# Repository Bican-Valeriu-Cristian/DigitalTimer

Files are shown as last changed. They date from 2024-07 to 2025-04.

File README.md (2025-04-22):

# Digital Timer

The project involves a digital timer that counts up to one minute. Each counter's 4-bit output is fed into a binary-to-7-segment decoder, enabling number display on 7-segment displays. 
The circuit includes switches for starting/stopping the timer and resetting the count.

WhatsApp Image 2024-07-15 at 16 40 44_299e31ab

## Description

This circuit diagram represents a digital timer capable of counting seconds up to one minute. The circuit operates by generating a clock signal with a precise frequency of 1 Hz (once per second) using an oscillator based on the NE555 timer. This signal is connected to the count-up input of an integrated circuit counter. Since the counter dedicated to seconds has a 4-bit output, it can count up to 15. Therefore, it requires conditioning with logic circuits to prevent it from exceeding the value of 10. Each time this number is reached, a count-up signal is also sent to a second counter dedicated to tens of seconds. This counter also requires logic conditioning, but this time up to the value of 6.

The 4 bits produced by each counter are then fed into a binary-to-7-segment decoder, which finally allows the numbers to be displayed on 7-segment displays. Additionally, the circuit includes two switches, one for starting and stopping the timer and another for resetting the count.

## Contents

| File/folder | Description |
|---|---|
| `PCB.kicad_sch` | Schematic |
| `PCB.kicad_pcb` | PCB editor |
| `gerber` | Altium Designer schematics, PCB layout, and supporting project files
| `README.md` | This README file. |
| `LICENSE` | The license for the project. |

## Tools

First step:
The schematic for this project was created using KiCad software.


Next was drawing the layout:

  -The PCB is a 8 cm x 8 cm 2-layer board.

  -It has a GND copper plane on both layers.

  -All signal traces are 0.254 mm, while the 5V power trace is double the size, at 0.508 mm.

  -Proper names were added for the various components, along with description text and a nice drawing.

  

The final steps were to order the parts, the PCB, and assemble the board.

  -The various components were ordered from TME
  
  -The PCB was ordered from Jlcpcb

## Bill of materials

-2x 7-segment displays

-2x 10nF ceramic capacitors

-1x 1uF electrolytic capacitor

-2x push switches

-2x header pins

-2x 4-bit tri-state registers

-2x 4-bit BCD decoders

-2x 4-bit counters

-2x quad AND gate chips

-1x quad NOR gate chip

-1x dual JK flip-flop chip

-Various resistors

## Final statistics
  
Total hours of work:

  Designing schematic and testing: 3 hours
  
  Making layout: 3 hours
  
  Assembling PCB: 5 hours

## Extra photos

WhatsApp Image 2024-07-15 at 16 51 08_b6c535b6

WhatsApp Image 2024-07-15 at 16 51 08_239efd22

## License

For details on license, see LICENSE in this directory.

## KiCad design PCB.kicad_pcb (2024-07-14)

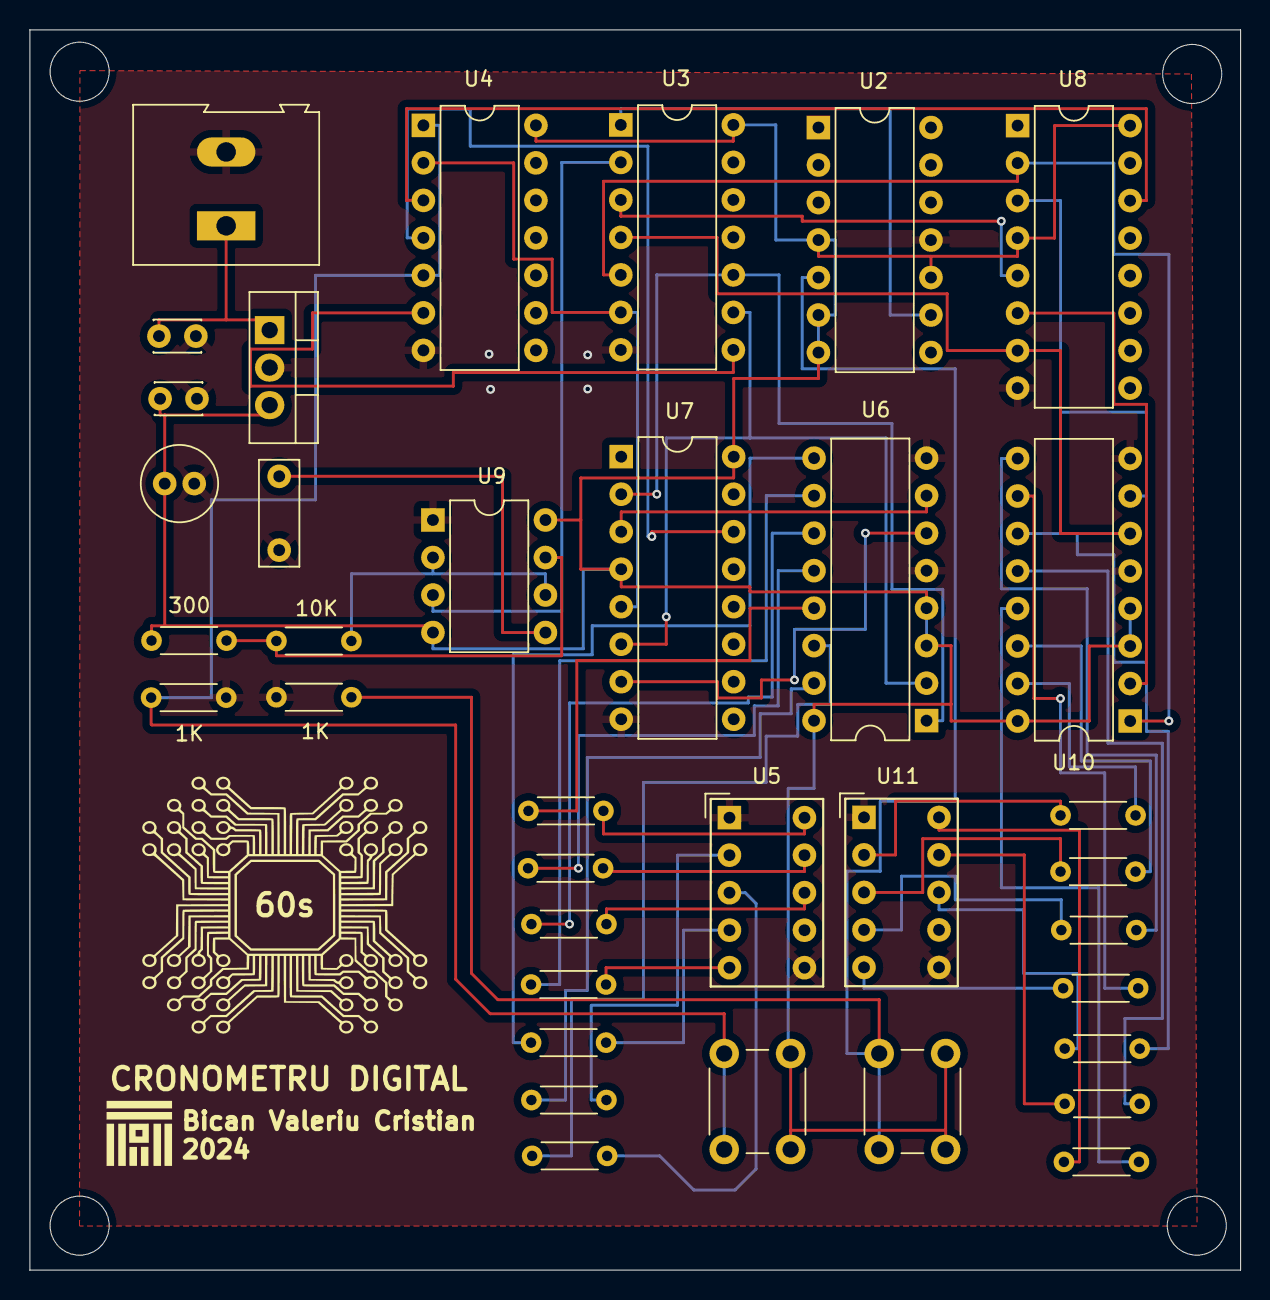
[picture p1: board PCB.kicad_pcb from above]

Board: 2 copper layers, 82.0 x 84.0 mm, 37 parts (0 on the bottom side), 51 nets.

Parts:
1K, 1K#2: 1k; R_Axial_DIN0204_L3.6mm_D1.6mm_P5.08mm_Horizontal
10K: 10k; R_Axial_DIN0204_L3.6mm_D1.6mm_P5.08mm_Horizontal
60s: LOGO; 2
300: 300; R_Axial_DIN0204_L3.6mm_D1.6mm_P5.08mm_Horizontal
C1, C2: 100n; C_Disc_D3.0mm_W2.0mm_P2.50mm
C3: 10n; C_Rect_L7.0mm_W2.5mm_P5.00mm
C4: 47u; C_Radial_D5.0mm_H11.0mm_P2.00mm
J1: Screw_Terminal_01x02; TerminalBlock_Altech_AK300-2_P5.00mm
R1, R2, R3, R4, R5, R6, R7, R8, R9, R10, R11, R12, R13, R14: 300R; R_Axial_DIN0204_L3.6mm_D1.6mm_P5.08mm_Horizontal
SW1, SW2: SW_Push; SW_PUSH_6mm
U1: L7805; TO-220-3_Vertical
U2: 74LS73; DIP-14_W7.62mm
U3: 74LS08; DIP-14_W7.62mm
U4: 4071; DIP-14_W7.62mm
U5, U11: HDSP-7403; HDSP-7401
U6, U10: 4511; DIP-16_W7.62mm
U7, U8: 74LS193; DIP-16_W7.62mm
U9: NE555D; DIP-8_W7.62mm

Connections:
+5V: 300.2, C1.1, C4.2, SW1.1, SW2.1, U1.3 (OUT), U2.4 (VCC), U2.6 (~R), U2.7 (J), U2.10 (K), U3.14 (VCC), U4.14 (VDD), U6.3 (~LT), U6.4 (~BI), U6.16 (Vdd), U7.4 (DOWN), U7.16 (VCC), U8.4 (DOWN), U8.16 (VCC), U9.4 (R), U9.8 (VCC), U10.3 (~LT), U10.4 (~BI), U10.16 (Vdd)
GND: 1K.2, 1K#2.2, C1.2, C2.2, C3.1, C4.1, J1.2, U1.2 (GND), U2.11 (GND), U3.7 (GND), U4.7 (VSS), U5.1 (CC), U5.6 (CC), U6.5 (~EL), U6.8 (Vss), U7.8 (GND), U8.8 (GND), U9.1 (GND), U10.5 (~EL), U10.8 (Vss), U11.1 (CC), U11.6 (CC)
unnamed: C2.1, J1.1, U1.1 (IN)
unnamed: 1K.1, SW1.2, U4.1, U4.5
unnamed: 1K#2.1, SW2.2, U2.5 (C)
unnamed: U2.9 (Q), U3.1
unnamed: U3.8, U4.6
unnamed: R1.2, U5.10 (A)
unnamed: R2.2, U5.9 (B)
unnamed: R3.2, U5.8 (C)
unnamed: R4.2, U5.5 (D)
unnamed: R5.2, U5.4 (E)
unnamed: R6.2, U5.2 (F)
unnamed: R7.2, U5.3 (G)
unnamed: U6.7 (DA), U7.3 (QA)
unnamed: U3.10, U6.1 (DB), U7.2 (QB)
unnamed: U3.9, U6.2 (DC), U7.6 (QC)
unnamed: U6.6 (DD), U7.7 (QD)
unnamed: R1.1, U6.13 (Qa)
unnamed: R2.1, U6.12 (Qb)
unnamed: R3.1, U6.11 (Qc)
unnamed: R4.1, U6.10 (Qd)
unnamed: R5.1, U6.9 (Qe)
unnamed: R6.1, U6.15 (Qf)
unnamed: R7.1, U6.14 (Qg)
unnamed: U4.4, U7.14 (CLR)
unnamed: U3.6, U4.2, U7.5 (UP)
unnamed: U4.3, U8.14 (CLR)
unnamed: U3.3, U8.5 (UP)
unnamed: C3.2, U9.5 (CV)
unnamed: 10K.2, 300.1, U9.7 (DIS)
unnamed: U3.2, U9.3 (Q)
unnamed: 10K.1, U9.2 (TR), U9.6 (THR)
unnamed: U8.3 (QA), U10.7 (DA)
unnamed: U3.5, U8.2 (QB), U10.1 (DB)
unnamed: U8.6 (QC), U10.2 (DC)
unnamed: U3.4, U8.7 (QD), U10.6 (DD)
unnamed: R8.1, U10.13 (Qa)
unnamed: R9.1, U10.12 (Qb)
unnamed: R10.1, U10.11 (Qc)
unnamed: R11.1, U10.10 (Qd)
unnamed: R12.1, U10.9 (Qe)
unnamed: R13.1, U10.15 (Qf)
unnamed: R14.1, U10.14 (Qg)
unnamed: R8.2, U11.10 (A)
unnamed: R9.2, U11.9 (B)
unnamed: R10.2, U11.8 (C)
unnamed: R11.2, U11.5 (D)
unnamed: R12.2, U11.4 (E)
unnamed: R13.2, U11.2 (F)
unnamed: R14.2, U11.3 (G)

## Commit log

2024-07-14 Update and rename practica.kicad_sch to PCB.kicad_sch
    [PCB.kicad_sch]
2024-07-14 Update and rename practica.kicad_pcb to PCB.kicad_pcb
    [PCB.kicad_pcb]
